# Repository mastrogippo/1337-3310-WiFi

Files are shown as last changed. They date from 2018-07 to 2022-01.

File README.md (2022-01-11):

## 1337 3310 WiFi PCB and schematics

Writeup and pics [here](http://www.mastrogippo.it/2018/07/more-adventures-with-nokia-3310-teaser/) and [here](http://www.mastrogippo.it/2018/07/1337-3310-wifi-hardware-design/)

ESP32 firmware [here](https://github.com/IHCcamp/ihc-badge-esp32)

STM32 firmware [here](https://github.com/IHCcamp/ihc-badge-STM32)

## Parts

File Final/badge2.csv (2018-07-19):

 | Qty | Value | Device | Package | Parts | Description | ARROW_PART_NUMBER | ARROW_PRICE/STOCK | DESCRIPTION | HEIGHT | MANUFACTURER_NAME | MANUFACTURER_PART_NUMBER | MPN | OC_FARNELL | OC_NEWARK | PACKAGE | PROD_ID | RS_PART_NUMBER | RS_PRICE/STOCK | SF_ID | SPICEPREFIX | SUPPLIER | VALUE
x | 1 |  | CONN_01POGOPIN_HOLE_0.58 | 1X01_POGOPIN_HOLE_0.58_DIA | J3 | Single connection point. Often used as Generic Header-pin footprint for 0.1 inch spaced/style header connections
x | 1 |  | USB_MICRO-B_SMT | USB-MICROB | J1 | USB Type Micro-B Connector |  |  |  |  |  |  |  |  |  |  | CONN-09505 |  |  | PRT-08533
x | 1 | 0 | R-EU_R0603 | R0603 | R10 | RESISTOR, European symbol |  |  |  |  |  |  |  |  |  |  |  |  |  |  | R
x | 1 | 1.6nH | C-EUC0603K | C0603K | L1 | CAPACITOR, European symbol |  |  |  |  |  |  |  |  |  |  |  |  |  |  | C
x | 5 | 100K 1/10W | SMD-RES-100K-5%-1/10W(0603) | R0603 | R12, R13, R14, R15, R17 | 301010089 |  |  |  |  |  |  | RC0603JR-07100KL |  |  |  |  |  |  |  |  |  | 100K 1/10W
x | 9 | 100nf | CERAMIC-100NF-50V-10%-X7R(0603) | C0603 | C5, C9, C10, C11, C15, C19, C20, C22, C25 | 302010138 |  |  |  |  |  |  | CC0603KRX7R9BB104 |  |  |  |  |  |  |  |  |  | 100nf
x | 6 | 10K | SMD-RES-10K-1%-1/10W(0603) | R0603 | R5, R9, R11, R16, R18, R19 | 301010299 |  |  |  |  |  |  | RC0603FR-0710KL |  |  |  |  |  |  |  |  |  | 10K
x | 1 | 10K | SMD-RES-10K-5%-1/10W(0603) | R0603 | R8 | 301010293 |  |  |  |  |  |  | RC0603JR-0710KL |  |  |  |  |  |  |  |  |  | 10K 1/10W
x | 2 | 18pF | 18PF-0603-50V-5% | 603 | C12, C13 | 18pF ceramic capacitors |  |  |  |  |  |  |  |  |  |  | CAP-08267 |  |  |  |  |  | 18pF
x | 1 | 2.7p | C-EUC0603 | C0603 | C16 | CAPACITOR, European symbol |  |  |  |  |  |  |  |  |  |  |  |  |  |  | C
x | 4 | 22R | SMD-RES-22R-5%-1/10W(0603) | R0603 | R1, R2, R6, R7 | 301010289 |  |  |  |  |  |  | RC0603JR-0722RL |  |  |  |  |  |  |  |  |  | 22R
x | 3 | 22uf | TANTALUM-SMD-22UF-16V(AVX-B) | AVX-B | C18, C23, C24 | 302020013 |  |  |  |  |  |  | TAJB226*016#NJ |  |  |  |  |  |  |  |  |  | 22uf
x | 1 | 2K | SMD-RES-1.5K-1%-1/10W(0603) | R0603 | R3 | 301010189 |  |  |  |  |  |  | RC0603FR-071K5L |  |  |  |  |  |  |  |  |  | 1.5K
x | 1 | 2K | SMD-RES-2K-1%-1/10W(0603) | R0603 | R4 | 301010221 |  |  |  |  |  |  | RC0603FR-072KL |  |  |  |  |  |  |  |  |  | 2K
x | 1 | 3310PANEL | 3310PANEL | 3310LCD | U$1
x | 1 | 4.7PF | CERAMIC-4.7PF-50V-0.25PF-NPO(0603) | C0603 | C17 | 302010091 |  |  |  |  |  |  | CC0603CRNPO9BN4R7 |  |  |  |  |  |  |  |  |  | 4.7PF
x | 1 | 4.7uf | CERAMIC-10UF-10V-10%-X5R(0603) | C0603 | C14 | 302010103 |  |  |  |  |  |  | CC0603KRX5R6BB106 |  |  |  |  |  |  |  |  |  | 10uf
x | 9 | 4.7uf | CERAMIC-4.7UF-10V-10%-X5R(0603) | C0603 | C1, C2, C3, C4, C6, C7, C8, C21, C26 | 302010111 |  |  |  |  |  |  | CC0603KRX5R6BB475 |  |  |  |  |  |  |  |  |  | 4.7uf
x | 1 | 8MHz | CRYSTAL-8MHZSMD-5X3.2 | CRYSTAL-SMD-5X3.2-4PAD | Y1 | 8MHz Crystal |  |  |  |  |  |  |  |  |  |  | XTAL-09431 |  |  |  |  |  | 8MHz
x | 3 | CJ2302 | SMD-MOSFET-N-CH-20V-2.1A-CJ2302(SOT-23) | SOT-23 | Q1, Q2, Q4 | 305030015 |  |  |  |  |  |  | CJ2302 |  |  |  |  |  |  |  |  |  | CJ2302
x | 1 | CJT1117-3.3-SOT223 | PMIC-CJT1117-3.3(SOT223) | SOT-223 | U$6 | 310030097 |  |  |  |  |  |  | CJT1117-3.3 |  |  |  |  |  |  |  |  |  | CJT1117-3.3-SOT223
x | 1 | ESP32-PICO-D4 | ESP32-PICO-D4 | ESP32-PICO-D4_1 | IC1 | ESP32-PICO-D4 module | ESP32-PICO-D4 |  | ESP32-PICO-D4 module | mm | Espressif | ESP32-PICO-D4
x | 1 | FDN340P | SMD-MOSFET-P-CH-20V-2A-FDN340P(SOT-23) | SOT-23 | Q3 | 305030026 |  |  |  |  |  |  | FDN340P |  |  |  |  |  |  |  |  |  | FDN340P
x | 3 | FIDUCIAL1.5X3 | FIDUCIAL1.5X3 | FIDUCIAL-1.5X3 | FID1, FID2, FID3 | Fiducial Alignment Points
x | 1 | INVERTED_F_ANTENNA+2 | INVERTED_F_ANTENNA+2 | DN007+2 | U$3 | 2.4GHz Inverted F Antenna
x | 1 | JST-09-PIN-HORIZONTAL | JST-09-PIN-HORIZONTAL | JST-09-SMD-HORI-1.0MM | U$4
x | 4 | LED-BOTTOM-1206 | LED-BOTTOM-1206 | LED-1206 | D4, D5, D6, D7
x | 1 | MCP73831 | MCP73831 | SOT23-5 | U3 | MCP73831T Li-Ion, Li-Pol Controller |  |  |  |  |  |  |  |  |  |  | IC-09995
x | 3 | NRVTS245ESFT3G | SMD-DIODE-SCHOTTKY-20V-1A(SOD-123) | SOD-123 | D1, D2, D3 | 304020034 |  |  |  |  |  |  | B5819W |  |  |  |  |  |  |  |  |  | 20V-1A
x | 1 | STM32F103CBT6 | STM32F103CBT6 | QFP50P900X900X160-48N | U2 | Medium-density performance line ARM-based 32-bit MCU |  |  |  |  |  |  | STM32F103CBT6 | 1606327 | 11N8296 | QFP-48 |  |  |  |  |  | STMICROELECTRONICS
x | 6 | TEST-POINT3X4 | TEST-POINT3X4 | PAD.03X.04 | TP1, TP2, TP3, TP4, TP5, TP6 | SparkFun Test Points
x | 1 | U-FL | ANTENNA-CONN-U-FL(3P) | U-FL3P-SMD-2.6X2.6X1.0MM | ANT1 | 320110048 |  |  |  |  |  |  |  |  |  |  |  |  |  |  |  |  | U-FL
x | 1 | WIRELESS-LORA-RFM95W#SMD | WIRELESS-LORA-RFM95W#SMD | WIRELESS-LORA-RFM95W#SMD | U$2 | 868/915 MHz LoRa Radio Transceiver Module based on SX1276 chip

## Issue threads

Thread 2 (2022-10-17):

Ordering the pcb's

sgoudsme, 2022-10-17:
Hi,
I'm interested in building one of these 3310 ESP boards.
I'm a  software engineer, familiar with esp-idf on eps32. So, programming the espressif will not be a problem.
I just want to know: I see that you describe some "problems" in the pcb, probably because it was the first prototype. But I see that (comparing the foto's and the gerber files) there is eg a ufl connector on gerber. Does this mean you have fixed the problems, but not tested them?
The thing I want the know in essence, If i order the pcb's online via eg jlcpcb, do you think there is a need of a rework or should it work as is? I don't need any guarantees, but more knowing that -as good as you've tested it- that it should work?

I don't find any contact information of you, you can always contact me at sibrecht@goudsmedt.be

Regards,
Sibrecht

mastrogippo, 2022-10-19:
Hi Sibrecht, as far as I remember, in the latest version everything works except for the buzzer. You'll have to short C26 and make sure you don't turn on the buzzer pin with a DC signal, or you'll burn it (it's a speaker, not a piezo).
I should have some spare PCBs, I can send you some if you cover shipping costs. Feel free to write me at [my name]@[my name].it
Cheers

Closed 2022-10-19.

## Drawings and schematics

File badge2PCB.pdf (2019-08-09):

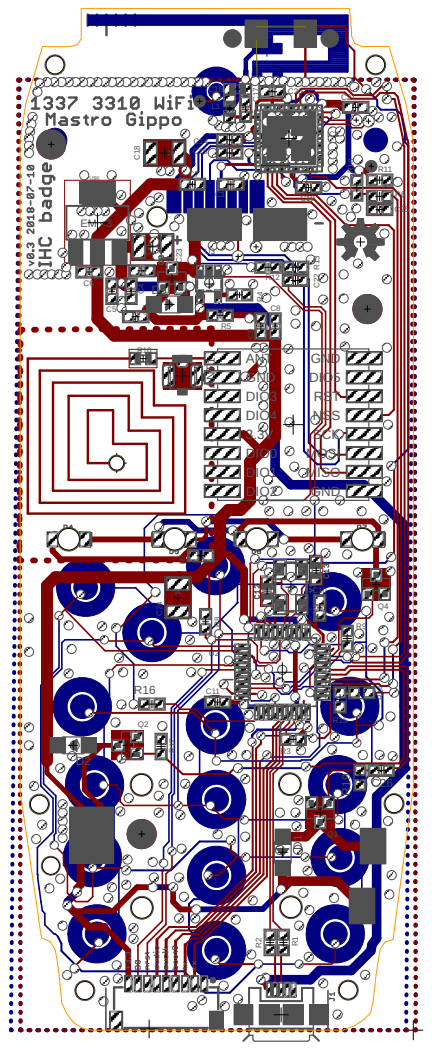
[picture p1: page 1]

GND MISO MOSI SCK NSS RST DIO5 GND
3.3V DIO4 DIO3 GND

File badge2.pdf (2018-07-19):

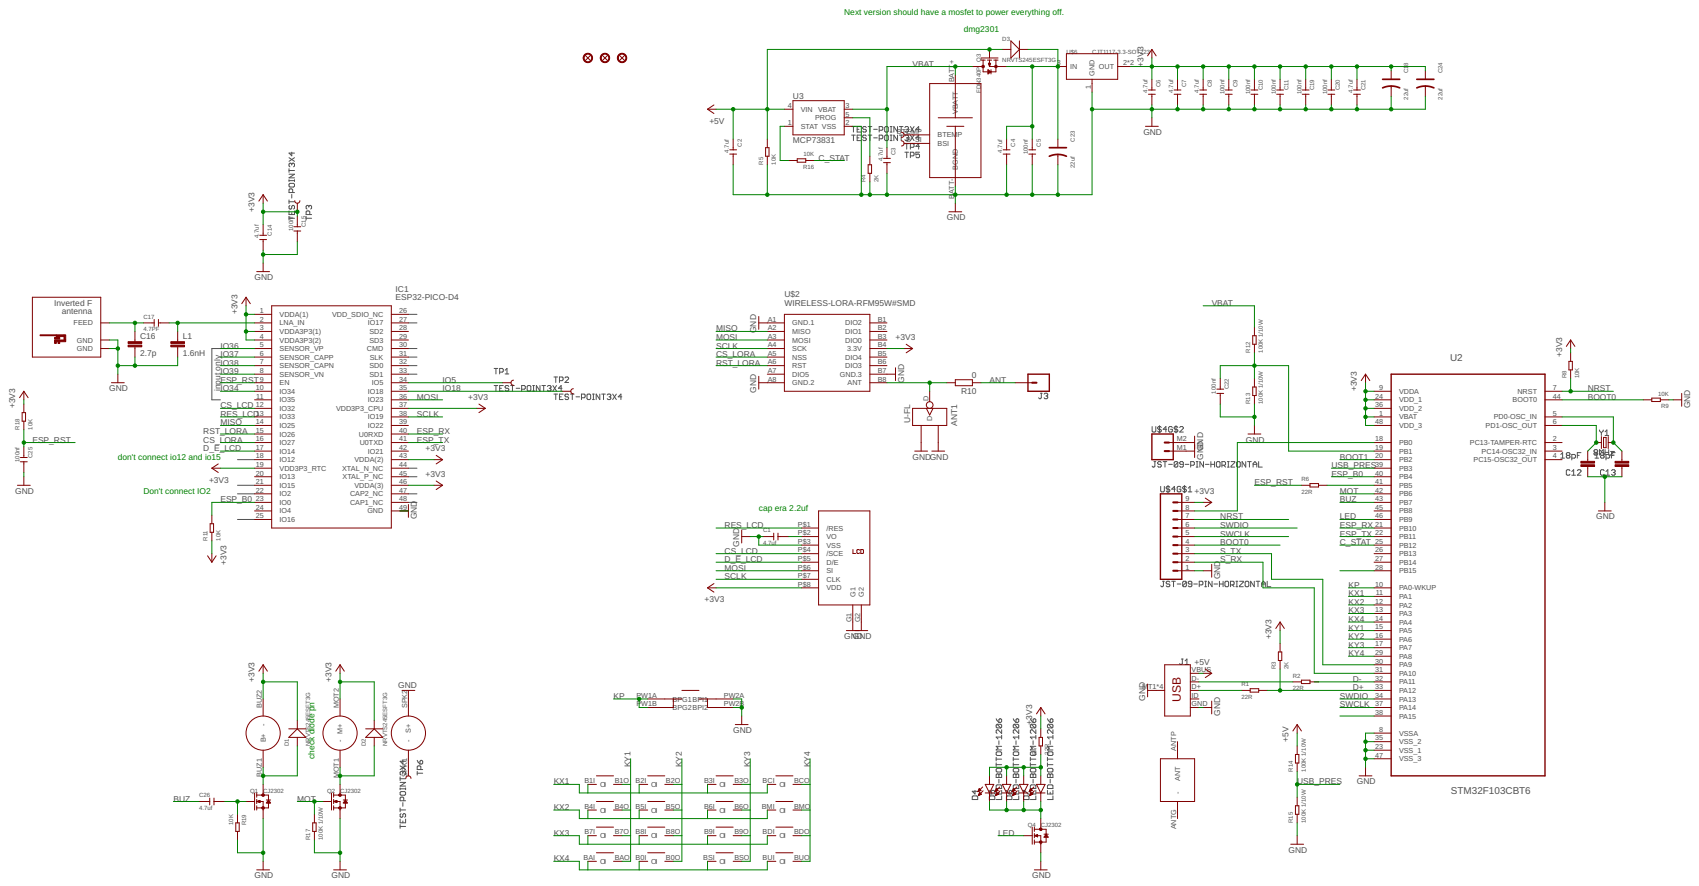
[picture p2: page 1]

Next version should have a mosfet to power everything off.

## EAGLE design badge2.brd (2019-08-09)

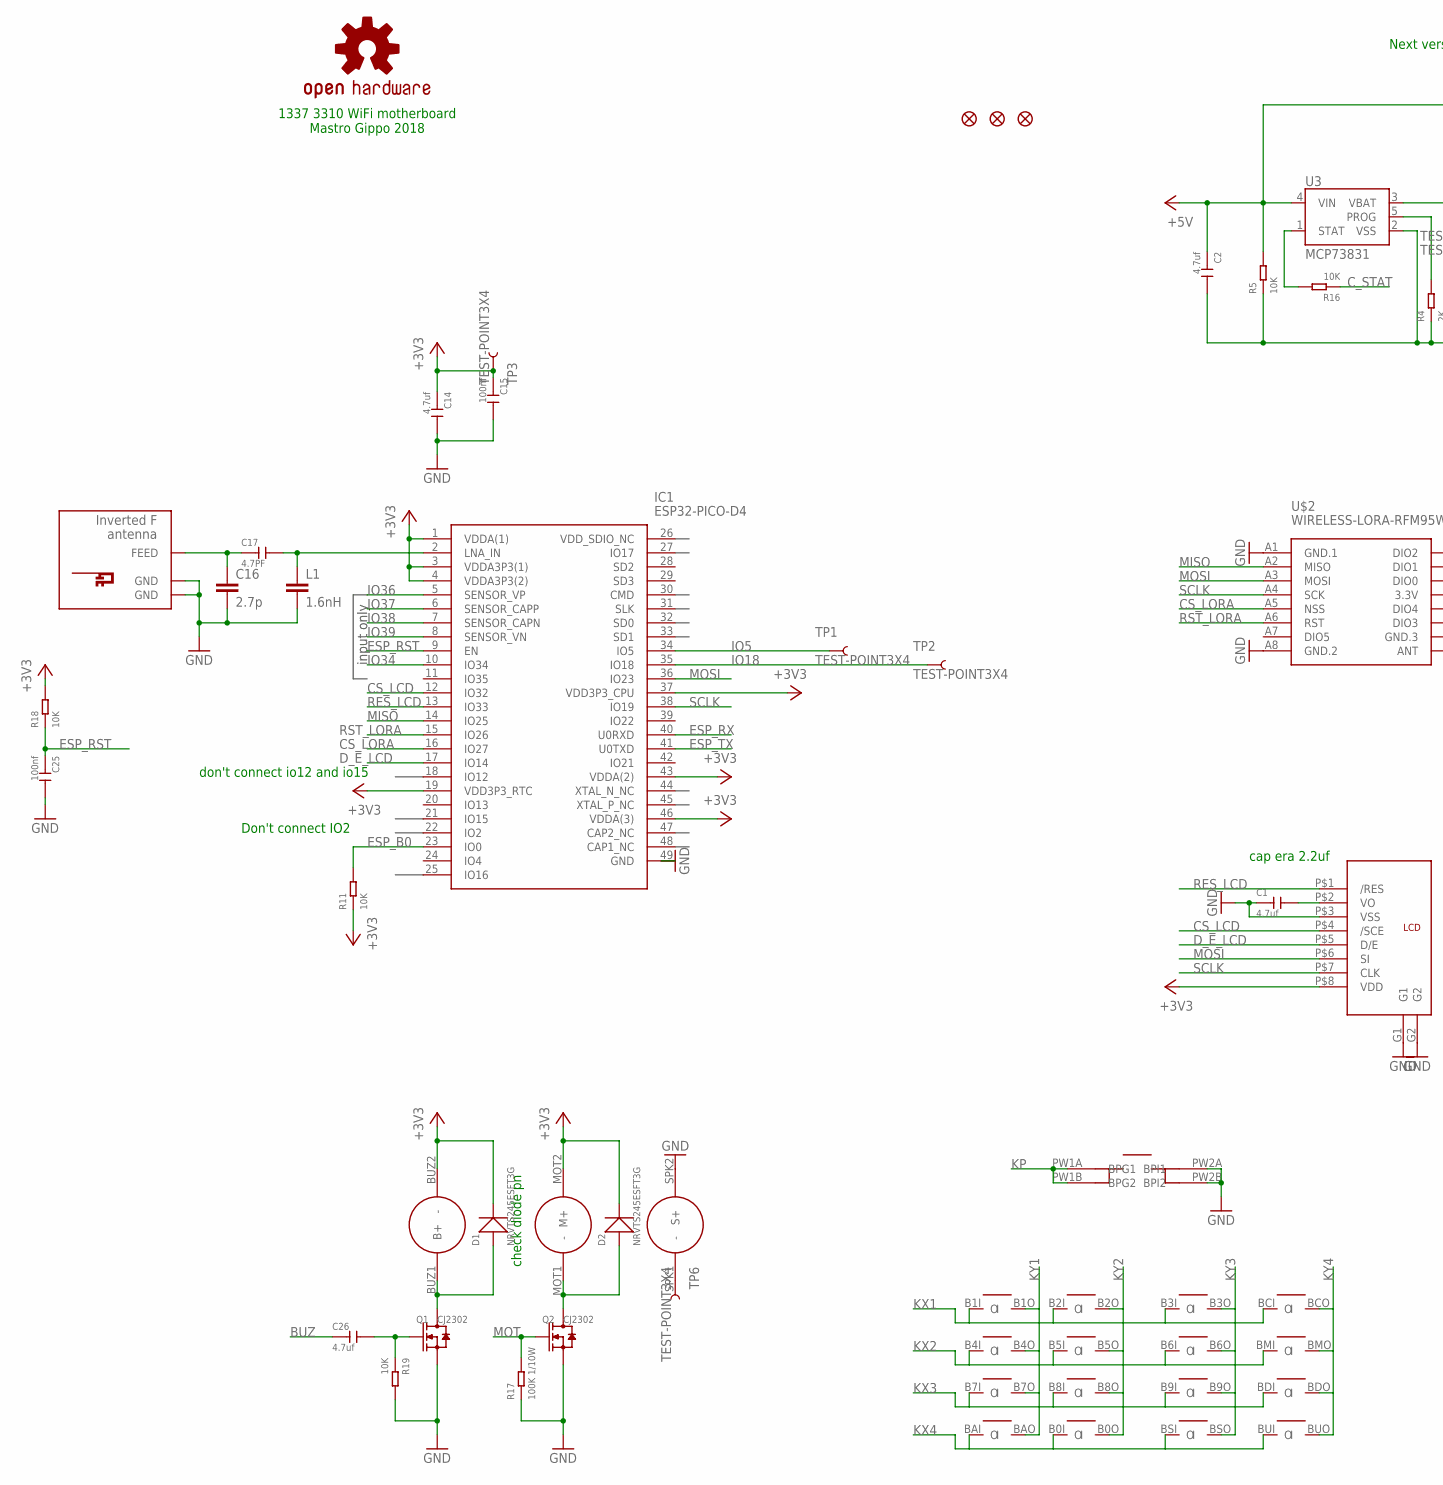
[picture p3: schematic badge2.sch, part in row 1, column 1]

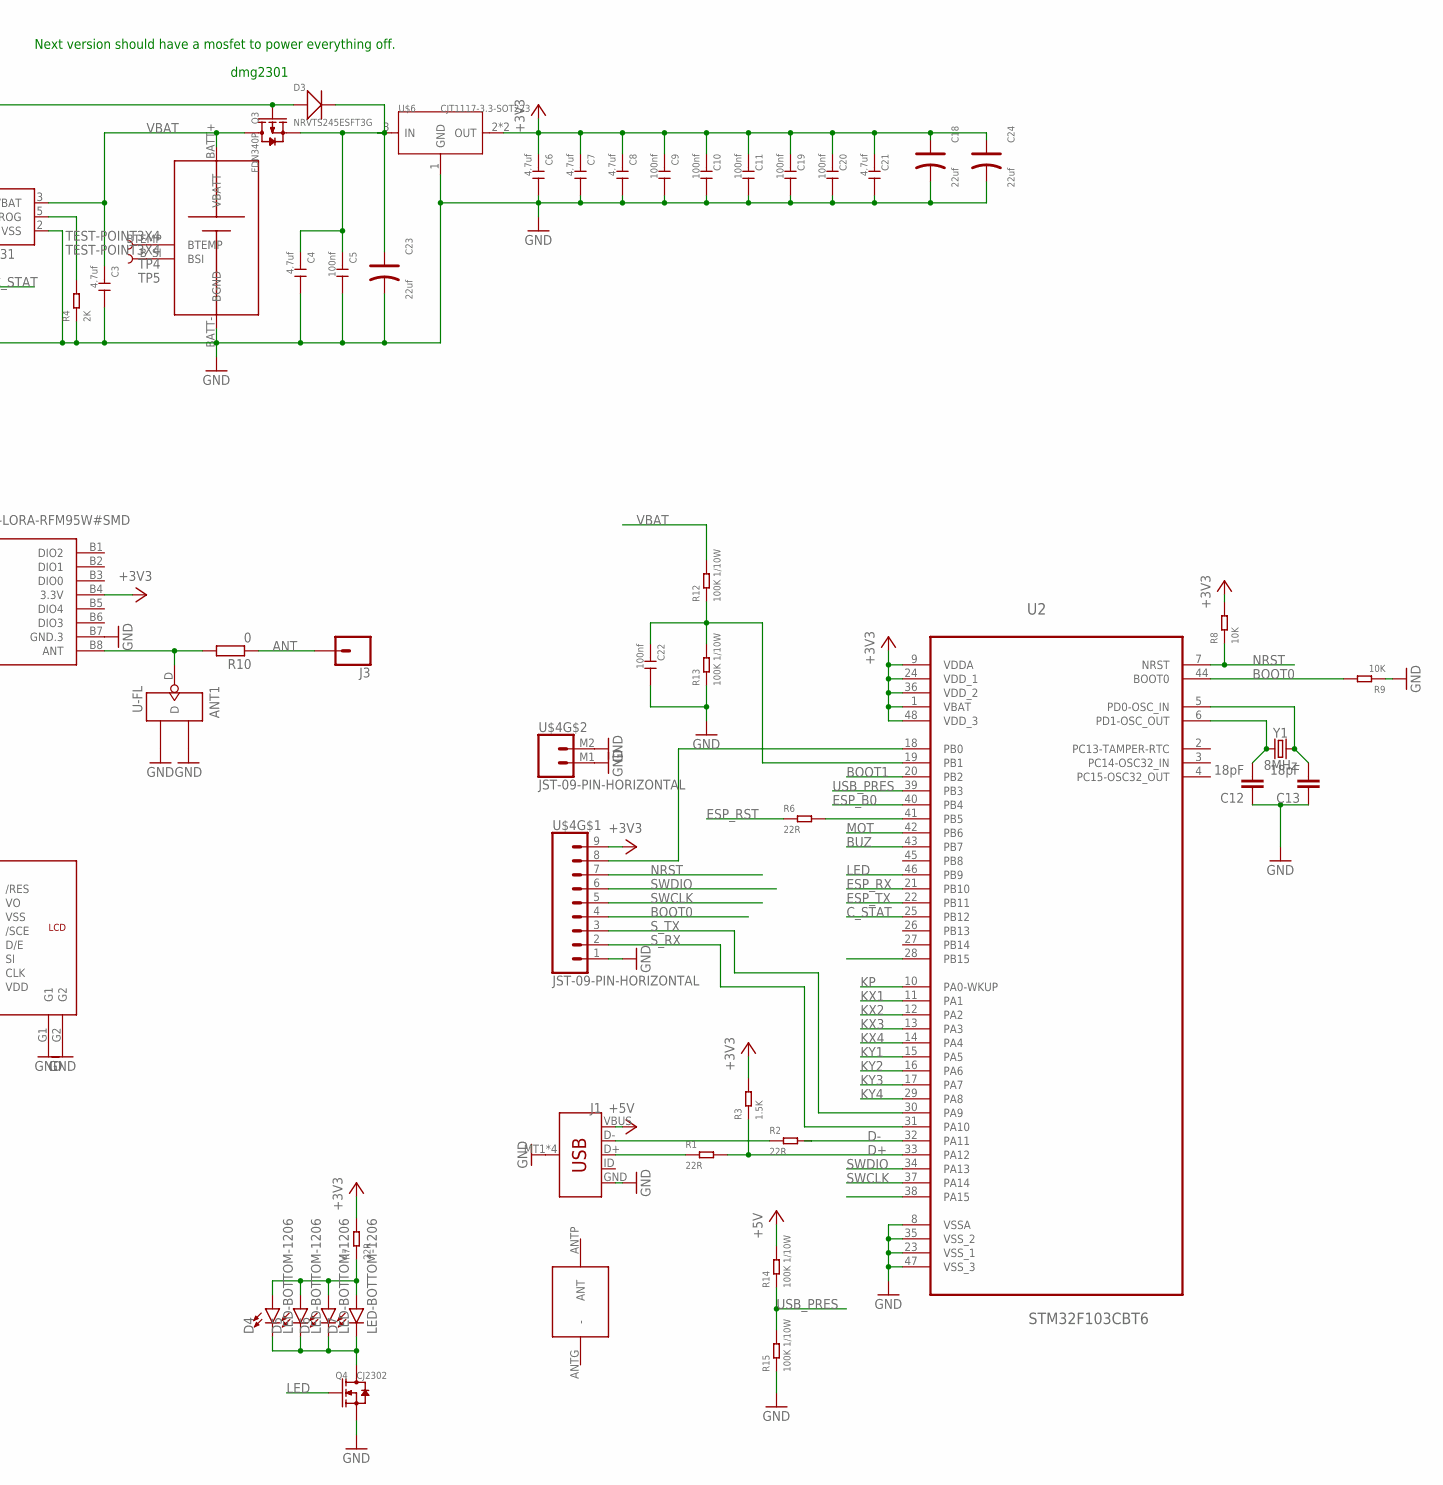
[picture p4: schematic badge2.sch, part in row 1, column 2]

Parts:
ANT1: U-FL; U-FL3P-SMD-2.6X2.6X1.0MM
C1, C2, C3, C4, C6, C7, C8, C14, C21, C26: 4.7uf; C0603
C5, C9, C10, C11, C15, C19, C20, C22, C25: 100nf; C0603
C12, C13: 18pF; 0603
C16: 2.7p; C0603
C17: 4.7PF; C0603
C18, C23, C24: 22uf; AVX-B
D1, D2, D3: NRVTS245ESFT3G; SOD-123
D4, D5, D6, D7: LED-BOTTOM-1206; LED-1206
FID1, FID2, FID3: FIDUCIAL1.5X3; FIDUCIAL-1.5X3
IC1: ESP32-PICO-D4; ESP32-PICO-D4_1
J1: USB_MICRO-B_SMT; USB-MICROB
J3: CONN_01POGOPIN_HOLE_0.58; 1X01_POGOPIN_HOLE_0.58_DIA
L1: 1.6nH; C0603K
LOGO1: OSHW-LOGOM; OSHW-LOGO-M
Q1, Q2, Q4: CJ2302; SOT-23
Q3: FDN340P; SOT-23
R1, R2, R6, R7: 22R; R0603
R3: 1.5K; R0603
R4: 2K; R0603
R5, R8, R9, R11, R16, R18, R19: 10K; R0603
R10: 0; R0603
R12, R13, R14, R15, R17: 100K 1/10W; R0603
TP1, TP2, TP3, TP4, TP5, TP6: TEST-POINT3X4; PAD.03X.04
U2: STM32F103CBT6; QFP50P900X900X160-48N
U3: MCP73831; SOT23-5
U$1: 3310PANEL; 3310LCD
U$2: WIRELESS-LORA-RFM95W#SMD
U$3: INVERTED_F_ANTENNA+2; DN007+2
U$4: JST-09-PIN-HORIZONTAL; JST-09-SMD-HORI-1.0MM
U$6: CJT1117-3.3-SOT223; SOT-223
Y1: 8MHz; CRYSTAL-SMD-5X3.2-4PAD

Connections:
+3V3: C6.1, C7.1, C8.1, C9.1, C10.1, C11.1, C14.1, C15.1, C18.+, C19.1, C20.1, C21.1, C24.+, D1.-, D2.-, IC1.1 (VDDA(1)), IC1.3 (VDDA3P3(1)), IC1.4 (VDDA3P3(2)), IC1.19 (VDD3P3_RTC), IC1.37 (VDD3P3_CPU), IC1.43 (VDDA(2)), IC1.46 (VDDA(3)), R3.2, R7.2, R8.2, R11.1, R18.2, TP3.P$1, U2.1 (VBAT), U2.9 (VDDA), U2.24 (VDD_1), U2.36 (VDD_2), U2.48 (VDD_3), U$1.BUZ2 (-), U$1.MOT2 (M+), U$1.P$8 (VDD), U$2.B4 (3.3V), U$4.9, U$6.2 (OUT), U$6.TER (OUT)
+5V: C2.1, D3.+, J1.VBUS, Q3.1 (G), R5.2, R14.2, U3.4 (VIN)
ANT: J3.1, R10.1
BOOT0: R9.2, U2.44 (BOOT0), U$4.4
BOOT1: U2.20 (PB2)
BUZ: C26.1, U2.43 (PB7)
CS_LCD: IC1.12 (IO32), U$1.P$4 (/SCE)
CS_LORA: IC1.16 (IO27), U$2.A5 (NSS)
C_STAT: R16.1, U2.25 (PB12)
D+: R1.2, R3.1, U2.33 (PA12)
D-: R2.2, U2.32 (PA11)
D_E_LCD: IC1.17 (IO14), U$1.P$5 (D/E)
ESP_B0: IC1.23 (IO0), R11.2, U2.40 (PB4)
ESP_RST: C25.1, IC1.9 (EN), R6.1, R18.1
ESP_RX: IC1.40 (U0RXD), U2.21 (PB10)
ESP_TX: IC1.41 (U0TXD), U2.22 (PB11)
GND: ANT1.GND1, ANT1.GND2, C1.1, C2.2, C3.2, C4.2, C5.2, C6.2, C7.2, C8.2, C9.2, C10.2, C11.2, C12.1, C13.1, C14.2, C15.2, C16.2, C18.-, C19.2, C20.2, C21.2, C22.2, C23.-, C24.-, C25.2, IC1.49 (GND), J1.GND, J1.MT1 (SHIELD), J1.MT2 (SHIELD), J1.P$1 (SHIELD), J1.P$2 (SHIELD), L1.2, Q1.2 (S), Q2.2 (S), Q4.2 (S), R4.1, R5.1, R9.1, R13.1, R15.1, R17.1, R19.2, U2.8 (VSSA), U2.23 (VSS_1), U2.35 (VSS_2), U2.47 (VSS_3), U3.2 (VSS), U$1.BATT- (BGND), U$1.G1, U$1.G2, U$1.P$3 (VSS), U$1.PW2A (BPI1), U$1.PW2B (BPI2), U$1.SPK2 (S+), U$2.A1 (GND.1), U$2.A8 (GND.2), U$2.B7 (GND.3), U$3.GND, U$3.GND@1 (GND), U$4.1, U$4.M1 (1), U$4.M2 (2), U$6.1 (GND)
IO5: IC1.34 (IO5), TP1.P$1
IO18: IC1.35 (IO18), TP2.P$1
IO34: IC1.10 (IO34)
IO36: IC1.5 (SENSOR_VP)
IO37: IC1.6 (SENSOR_CAPP)
IO38: IC1.7 (SENSOR_CAPN)
IO39: IC1.8 (SENSOR_VN)
KP: U2.10 (PA0-WKUP), U$1.PW1A (BPG1), U$1.PW1B (BPG2)
KX1: U2.11 (PA1), U$1.B1I (I), U$1.B2I (I), U$1.B3I (I), U$1.BCI (I)
KX2: U2.12 (PA2), U$1.B4I (I), U$1.B5I (I), U$1.B6I (I), U$1.BMI (I)
KX3: U2.13 (PA3), U$1.B7I (I), U$1.B8I (I), U$1.B9I (I), U$1.BDI (I)
KX4: U2.14 (PA4), U$1.B0I (I), U$1.BAI (I), U$1.BSI (I), U$1.BUI (I)
KY1: U2.15 (PA5), U$1.B1O (O), U$1.B4O (O), U$1.B7O (O), U$1.BAO (O)
KY2: U2.16 (PA6), U$1.B0O (O), U$1.B2O (O), U$1.B5O (O), U$1.B8O (O)
KY3: U2.17 (PA7), U$1.B3O (O), U$1.B6O (O), U$1.B9O (O), U$1.BSO (O)
KY4: U2.29 (PA8), U$1.BCO (O), U$1.BDO (O), U$1.BMO (O), U$1.BUO (O)
LED: Q4.1 (G), U2.46 (PB9)
MISO: IC1.14 (IO25), U$2.A2 (MISO)
MOSI: IC1.36 (IO23), U$1.P$6 (SI), U$2.A3 (MOSI)
MOT: Q2.1 (G), R17.2, U2.42 (PB6)
unnamed: C1.2, U$1.P$2 (VO)
unnamed: C16.1, C17.1, U$3.FEED
unnamed: C17.2, IC1.2 (LNA_IN), L1.1
unnamed: ANT1.D, R10.2, U$2.B8 (ANT)
unnamed: J1.D+, R1.1
unnamed: J1.D-, R2.1
unnamed: R16.2, U3.1 (STAT)
unnamed: C26.2, Q1.1 (G), R19.1
unnamed: D1.+, Q1.3 (D), U$1.BUZ1 (B+)
unnamed: C13.2, U2.5 (PD0-OSC_IN), Y1.3 (2)
unnamed: TP4.P$1, U$1.BTEMP
unnamed: D2.+, Q2.3 (D), U$1.MOT1 (-)
unnamed: R4.2, U3.5 (PROG)
unnamed: C4.1, C5.1, C23.+, D3.-, Q3.2 (S), U$6.3 (IN)
unnamed: C12.2, U2.6 (PD1-OSC_OUT), Y1.1
unnamed: U2.18 (PB0), U$4.8
unnamed: TP6.P$1, U$1.SPK1 (-)
unnamed: R6.2, U2.41 (PB5)
unnamed: TP5.P$1, U$1.B_SI (BSI)
unnamed: D4.C, D5.C, D6.C, D7.C, Q4.3 (D)
unnamed: D4.A, D5.A, D6.A, D7.A, R7.1
unnamed: C22.1, R12.1, R13.2, U2.19 (PB1)
NRST: R8.1, U2.7 (NRST), U$4.7
RES_LCD: IC1.13 (IO33), U$1.P$1 (/RES)
RST_LORA: IC1.15 (IO26), U$2.A6 (RST)
SCLK: IC1.38 (IO19), U$1.P$7 (CLK), U$2.A4 (SCK)
SWCLK: U2.37 (PA14), U$4.5
SWDIO: U2.34 (PA13), U$4.6
S_RX: U2.31 (PA10), U$4.2
S_TX: U2.30 (PA9), U$4.3
USB_PRES: R14.1, R15.2, U2.39 (PB3)
VBAT: C3.1, Q3.3 (D), R12.2, U3.3 (VBAT), U$1.BATT+ (VBATT)

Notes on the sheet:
check diode pn
input only
Don't connect IO2
don't connect io12 and io15
dmg2301
cap era 2.2uf
Next version should have a mosfet to power everything off.
1337 3310 WiFi motherboard Mastro Gippo 2018

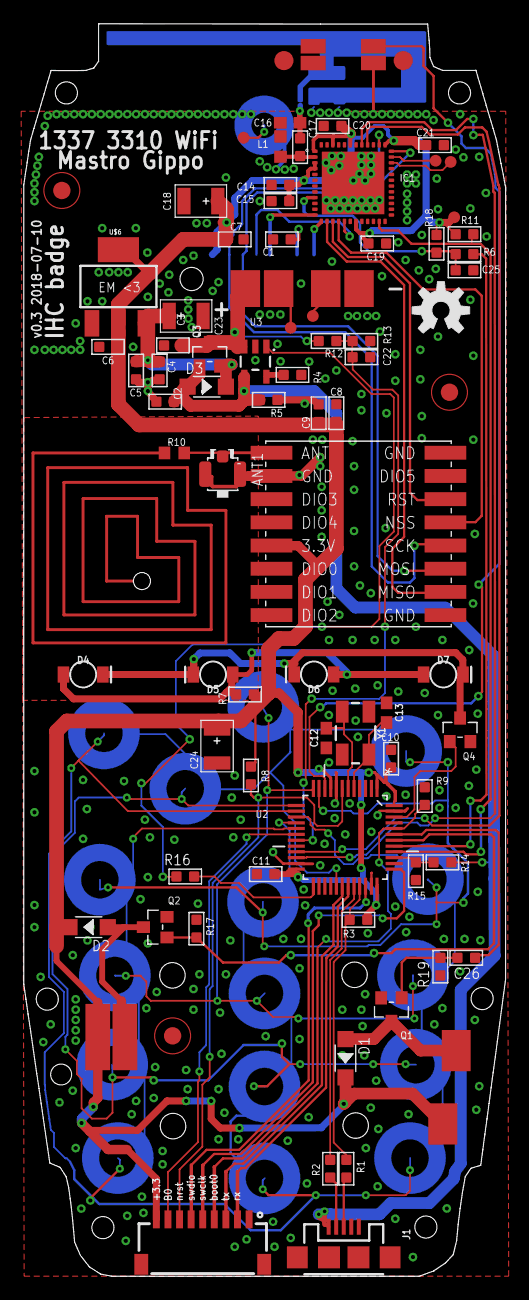
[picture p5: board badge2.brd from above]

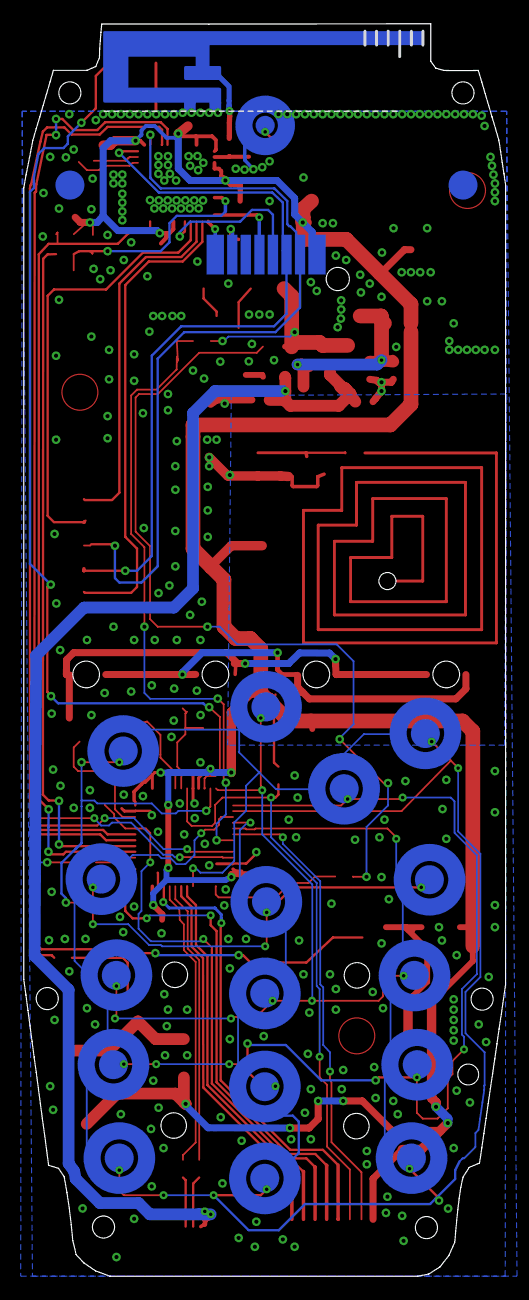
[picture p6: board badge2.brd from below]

Board: 2 copper layers, 41.6 x 108.0 mm, 79 parts (2 on the bottom side), 63 nets.

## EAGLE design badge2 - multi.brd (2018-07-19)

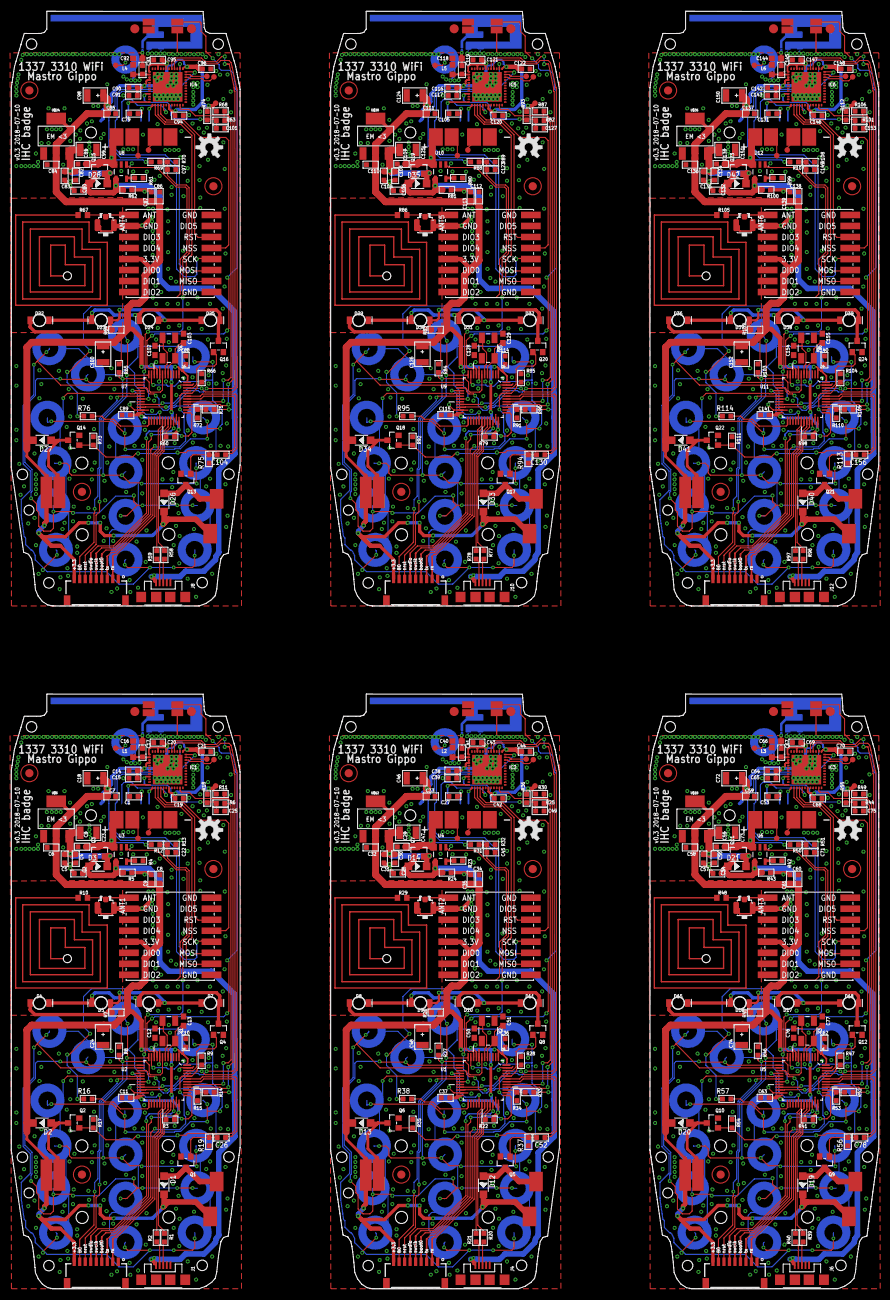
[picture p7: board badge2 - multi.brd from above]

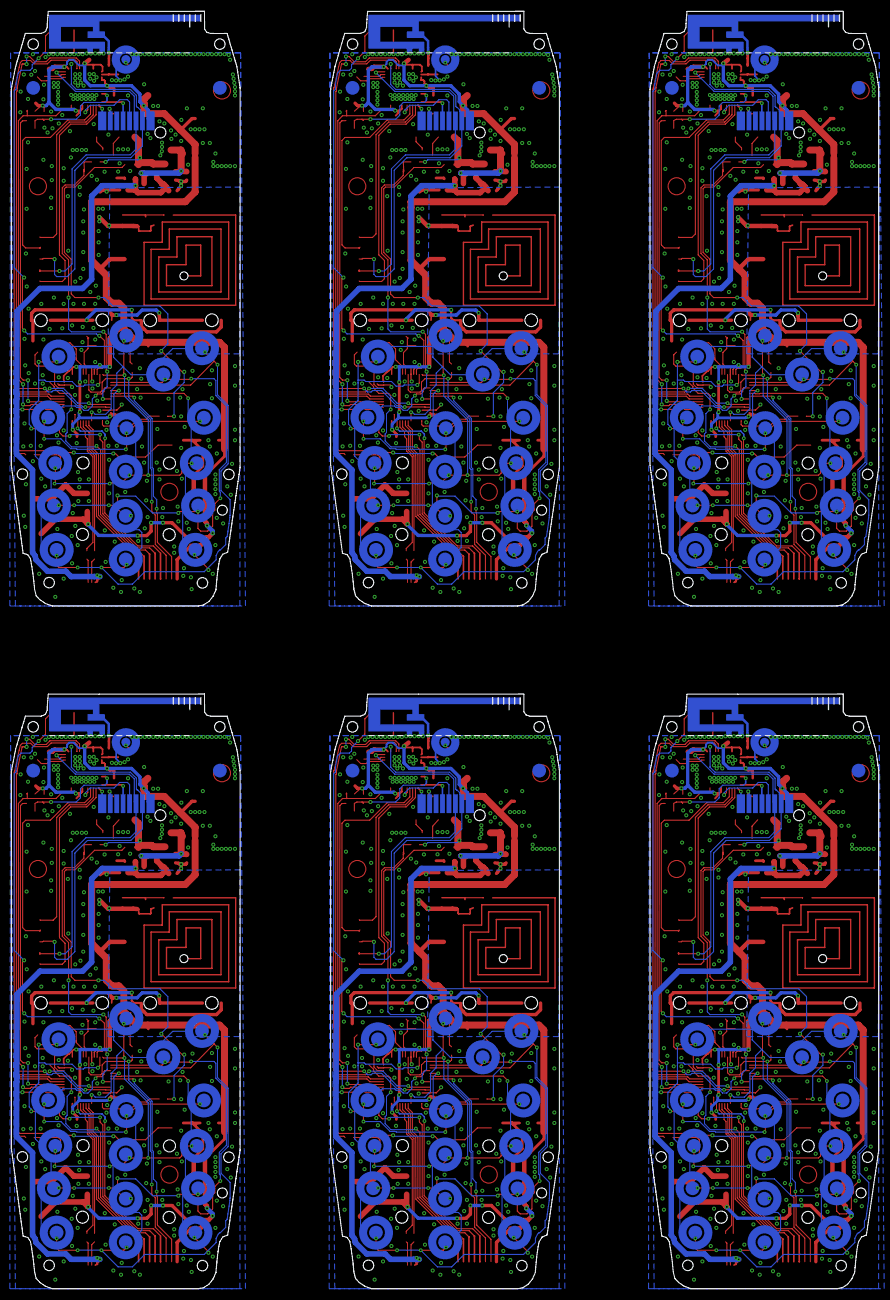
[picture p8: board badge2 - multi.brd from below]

Board: 2 copper layers, 474 parts (12 on the bottom side), 378 nets.

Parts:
ANT1, ANT2, ANT3, ANT4, ANT5, ANT6: U-FL; U-FL3P-SMD-2.6X2.6X1.0MM
C1, C2, C3, C4, C6, C7, C8, C21, C26, C27, C28, C29, C30, C32, C33, C34, C44, C52, C53, C54, C55, C56, C58, C59, C60, C70, C78, C79, C80, C81, C82, C84, C85, C86, C96, C104, C105, C106, C107, C108, C110, C111, C112, C122, C130, C131, C132, C133, C134, C136, C137, C138, C148, C156: 4.7uf; C0603
C5, C9, C10, C11, C15, C19, C20, C22, C25, C31, C35, C36, C37, C39, C42, C43, C45, C49, C57, C61, C62, C63, C65, C68, C69, C71, C75, C83, C87, C88, C89, C91, C94, C95, C97, C101, C109, C113, C114, C115, C117, C120, C121, C123, C127, C135, C139, C140, C141, C143, C146, C147, C149, C153: 100nf; C0603
C12, C13, C50, C51, C76, C77, C102, C103, C128, C129, C154, C155: 18pF; 0603
C14, C38, C64, C90, C116, C142: 10uf; C0603
C16, C40, C66, C92, C118, C144: 2.7p; C0603
C17, C41, C67, C93, C119, C145: 4.7PF; C0603
C18, C23, C24, C46, C47, C48, C72, C73, C74, C98, C99, C100, C124, C125, C126, C150, C151, C152: 22uf; AVX-B
D1, D2, D3, D12, D13, D14, D19, D20, D21, D26, D27, D28, D33, D34, D35, D40, D41, D42: NRVTS245ESFT3G; SOD-123
D4, D5, D6, D7, D8, D9, D10, D11, D15, D16, D17, D18, D22, D23, D24, D25, D29, D30, D31, D32, D36, D37, D38, D39: LED-BOTTOM-1206; LED-1206
FID1, FID2, FID3, FID4, FID5, FID6, FID7, FID8, FID9, FID10, FID11, FID12, FID13, FID14, FID15, FID16, FID17, FID18: FIDUCIAL1.5X3; FIDUCIAL-1.5X3
IC1, IC2, IC3, IC4, IC5, IC6: ESP32-PICO-D4; ESP32-PICO-D4_1
J1, J4, J6, J8, J10, J12: USB-MICROB
J2, J3, J5, J7, J9, J11: 1X01_POGOPIN_HOLE_0.58_DIA
L1, L2, L3, L4, L5, L6: 1.6nH; C0603K
Q1, Q2, Q4, Q5, Q6, Q8, Q9, Q10, Q12, Q13, Q14, Q16, Q17, Q18, Q20, Q21, Q22, Q24: CJ2302; SOT-23
Q3, Q7, Q11, Q15, Q19, Q23: FDN340P; SOT-23
R1, R2, R6, R7, R20, R21, R25, R26, R39, R40, R44, R45, R58, R59, R63, R64, R77, R78, R82, R83, R96, R97, R101, R102: 22R; R0603
R3, R22, R41, R60, R79, R98: 1.5K; R0603
R4, R23, R42, R61, R80, R99: 2K; R0603
R5, R9, R11, R16, R18, R19, R24, R28, R30, R36, R37, R38, R43, R47, R49, R55, R56, R57, R62, R66, R68, R74, R75, R76, R81, R85, R87, R93, R94, R95, R100, R104, R106, R112, R113, R114: 10K; R0603
R8, R27, R46, R65, R84, R103: 10K 1/10W; R0603
R10, R29, R48, R67, R86, R105: 0; R0603
R12, R13, R14, R15, R17, R31, R32, R33, R34, R35, R50, R51, R52, R53, R54, R69, R70, R71, R72, R73, R88, R89, R90, R91, R92, R107, R108, R109, R110, R111: 100K 1/10W; R0603
TP1, TP2, TP3, TP4, TP5, TP6, TP7, TP8, TP9, TP10, TP11, TP12, TP13, TP14, TP15, TP16, TP17, TP18, TP19, TP20, TP21, TP22, TP23, TP24, TP25, TP26, TP27, TP28, TP29, TP30, TP31, TP32, TP33, TP34, TP35, TP36: TEST-POINT3X4; PAD.03X.04
U1, U2, U5, U7, U9, U11: STM32F103CBT6; QFP50P900X900X160-48N
U3, U4, U6, U8, U10, U12: MCP73831; SOT23-5
U$1, U$7, U$13, U$19, U$25, U$31: 3310PANEL; 3310LCD
U$2, U$8, U$14, U$20, U$26, U$32: WIRELESS-LORA-RFM95W#SMD
U$3, U$9, U$15, U$21, U$27, U$33: INVERTED_F_ANTENNA+2; DN007+2
U$4, U$10, U$16, U$22, U$28, U$34: JST-09-PIN-HORIZONTAL; JST-09-SMD-HORI-1.0MM
U$5, U$11, U$17, U$23, U$29, U$35: OSHW-LOGO-M
U$6, U$12, U$18, U$24, U$30, U$36: CJT1117-3.3-SOT223; SOT-223
Y1, Y2, Y3, Y4, Y5, Y6: 8MHz; CRYSTAL-SMD-5X3.2-4PAD

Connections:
+3V1: C32.1, C33.1, C34.1, C35.1, C36.1, C37.1, C38.1, C39.1, C42.1, C43.1, C44.1, C46.+, C48.+, D12.-, D13.-, IC2.1, IC2.3, IC2.4, IC2.19, IC2.37, IC2.43, IC2.46, R22.2, R26.2, R27.2, R30.1, R36.2, TP9.P$1, U1.1, U1.9, U1.24, U1.36, U1.48, U$7.BUZ2, U$7.MOT2, U$7.P$8, U$8.B4, U$10.9, U$12.2, U$12.TER
+3V2: C58.1, C59.1, C60.1, C61.1, C62.1, C63.1, C64.1, C65.1, C68.1, C69.1, C70.1, C72.+, C74.+, D19.-, D20.-, IC3.1, IC3.3, IC3.4, IC3.19, IC3.37, IC3.43, IC3.46, R41.2, R45.2, R46.2, R49.1, R55.2, TP15.P$1, U5.1, U5.9, U5.24, U5.36, U5.48, U$13.BUZ2, U$13.MOT2, U$13.P$8, U$14.B4, U$16.9, U$18.2, U$18.TER
+3V3: C6.1, C7.1, C8.1, C9.1, C10.1, C11.1, C14.1, C15.1, C18.+, C19.1, C20.1, C21.1, C24.+, D1.-, D2.-, IC1.1, IC1.3, IC1.4, IC1.19, IC1.37, IC1.43, IC1.46, R3.2, R7.2, R8.2, R11.1, R18.2, TP3.P$1, U2.1, U2.9, U2.24, U2.36, U2.48, U$1.BUZ2, U$1.MOT2, U$1.P$8, U$2.B4, U$4.9, U$6.2, U$6.TER
+3V4: C84.1, C85.1, C86.1, C87.1, C88.1, C89.1, C90.1, C91.1, C94.1, C95.1, C96.1, C98.+, C100.+, D26.-, D27.-, IC4.1, IC4.3, IC4.4, IC4.19, IC4.37, IC4.43, IC4.46, R60.2, R64.2, R65.2, R68.1, R74.2, TP21.P$1, U7.1, U7.9, U7.24, U7.36, U7.48, U$19.BUZ2, U$19.MOT2, U$19.P$8, U$20.B4, U$22.9, U$24.2, U$24.TER
+3V5: C110.1, C111.1, C112.1, C113.1, C114.1, C115.1, C116.1, C117.1, C120.1, C121.1, C122.1, C124.+, C126.+, D33.-, D34.-, IC5.1, IC5.3, IC5.4, IC5.19, IC5.37, IC5.43, IC5.46, R79.2, R83.2, R84.2, R87.1, R93.2, TP27.P$1, U9.1, U9.9, U9.24, U9.36, U9.48, U$25.BUZ2, U$25.MOT2, U$25.P$8, U$26.B4, U$28.9, U$30.2, U$30.TER
+3V6: C136.1, C137.1, C138.1, C139.1, C140.1, C141.1, C142.1, C143.1, C146.1, C147.1, C148.1, C150.+, C152.+, D40.-, D41.-, IC6.1, IC6.3, IC6.4, IC6.19, IC6.37, IC6.43, IC6.46, R98.2, R102.2, R103.2, R106.1, R112.2, TP33.P$1, U11.1, U11.9, U11.24, U11.36, U11.48, U$31.BUZ2, U$31.MOT2, U$31.P$8, U$32.B4, U$34.9, U$36.2, U$36.TER
+5V: C2.1, D3.+, J1.VBUS, Q3.1, R5.2, R14.2, U3.4
+5V1: C28.1, D14.+, J4.VBUS, Q7.1, R24.2, R33.2, U4.4
+5V2: C54.1, D21.+, J6.VBUS, Q11.1, R43.2, R52.2, U6.4
+5V3: C80.1, D28.+, J8.VBUS, Q15.1, R62.2, R71.2, U8.4
+5V4: C106.1, D35.+, J10.VBUS, Q19.1, R81.2, R90.2, U10.4
+5V5: C132.1, D42.+, J12.VBUS, Q23.1, R100.2, R109.2, U12.4
ANT: J3.1, R10.1
ANT1: J2.1, R29.1
ANT2: J5.1, R48.1
ANT3: J7.1, R67.1
ANT4: J9.1, R86.1
ANT5: J11.1, R105.1
BOOT0: R9.2, U2.44, U$4.4
BOOT3: R28.2, U1.44, U$10.4
BOOT5: R47.2, U5.44, U$16.4
BOOT7: R66.2, U7.44, U$22.4
BOOT9: R85.2, U9.44, U$28.4
BOOT11: R104.2, U11.44, U$34.4
BUZ: C26.1, U2.43
BUZ1: C52.1, U1.43
BUZ2: C78.1, U5.43
BUZ3: C104.1, U7.43
BUZ4: C130.1, U9.43
BUZ5: C156.1, U11.43
CS_LCD: IC1.12, U$1.P$4
CS_LCD1: IC2.12, U$7.P$4
CS_LCD2: IC3.12, U$13.P$4
CS_LCD3: IC4.12, U$19.P$4
CS_LCD4: IC5.12, U$25.P$4
CS_LCD5: IC6.12, U$31.P$4
CS_LORA: IC1.16, U$2.A5
CS_LORA1: IC2.16, U$8.A5
CS_LORA2: IC3.16, U$14.A5
CS_LORA3: IC4.16, U$20.A5
CS_LORA4: IC5.16, U$26.A5
CS_LORA5: IC6.16, U$32.A5
C_STAT: R16.1, U2.25
C_STAT1: R38.1, U1.25
C_STAT2: R57.1, U5.25
C_STAT3: R76.1, U7.25
C_STAT4: R95.1, U9.25
C_STAT5: R114.1, U11.25
D+: R1.2, R3.1, U2.33
D+1: R20.2, R22.1, U1.33
D+2: R39.2, R41.1, U5.33
D+3: R58.2, R60.1, U7.33
D+4: R77.2, R79.1, U9.33
D+5: R96.2, R98.1, U11.33
D-: R2.2, U2.32
D-1: R21.2, U1.32
D-2: R40.2, U5.32
D-3: R59.2, U7.32
D-4: R78.2, U9.32
D-5: R97.2, U11.32
D_E_LCD: IC1.17, U$1.P$5
D_E_LCD1: IC2.17, U$7.P$5
D_E_LCD2: IC3.17, U$13.P$5
D_E_LCD3: IC4.17, U$19.P$5
D_E_LCD4: IC5.17, U$25.P$5
D_E_LCD5: IC6.17, U$31.P$5
ESP_B0: IC1.23, R11.2, U2.40
ESP_B1: IC2.23, R30.2, U1.40
ESP_B2: IC3.23, R49.2, U5.40
ESP_B3: IC4.23, R68.2, U7.40
ESP_B4: IC5.23, R87.2, U9.40
ESP_B5: IC6.23, R106.2, U11.40
ESP_RST: C25.1, IC1.9, R6.1, R18.1
ESP_RST1: C49.1, IC2.9, R25.1, R36.1
ESP_RST2: C75.1, IC3.9, R44.1, R55.1
ESP_RST3: C101.1, IC4.9, R63.1, R74.1
ESP_RST4: C127.1, IC5.9, R82.1, R93.1
ESP_RST5: C153.1, IC6.9, R101.1, R112.1
ESP_RX: IC1.40, U2.21
ESP_RX1: IC2.40, U1.21
ESP_RX2: IC3.40, U5.21
ESP_RX3: IC4.40, U7.21
ESP_RX4: IC5.40, U9.21
ESP_RX5: IC6.40, U11.21
ESP_TX: IC1.41, U2.22
ESP_TX1: IC2.41, U1.22
ESP_TX2: IC3.41, U5.22
ESP_TX3: IC4.41, U7.22
ESP_TX4: IC5.41, U9.22
ESP_TX5: IC6.41, U11.22
GND: ANT1.GND1, ANT1.GND2, C1.1, C2.2, C3.2, C4.2, C5.2, C6.2, C7.2, C8.2, C9.2, C10.2, C11.2, C12.1, C13.1, C14.2, C15.2, C16.2, C18.-, C19.2, C20.2, C21.2, C22.2, C23.-, C24.-, C25.2, IC1.49, J1.GND, J1.MT1, J1.MT2, J1.P$1, J1.P$2, L1.2, Q1.2, Q2.2, Q4.2, R4.1, R5.1, R9.1, R13.1, R15.1, R17.1, R19.2, U2.8, U2.23, U2.35, U2.47, U3.2, U$1.BATT-, U$1.G1, U$1.G2, U$1.P$3, U$1.PW2A, U$1.PW2B, U$1.SPK2, U$2.A1, U$2.A8, U$2.B7, U$3.GND, U$3.GND@1, U$4.1, U$4.M1, U$4.M2, U$6.1
GND1: ANT2.GND1, ANT2.GND2, C27.1, C28.2, C29.2, C30.2, C31.2, C32.2, C33.2, C34.2, C35.2, C36.2, C37.2, C38.2, C39.2, C40.2, C42.2, C43.2, C44.2, C45.2, C46.-, C47.-, C48.-, C49.2, C50.1, C51.1, IC2.49, J4.GND, J4.MT1, J4.MT2, J4.P$1, J4.P$2, L2.2, Q5.2, Q6.2, Q8.2, R23.1, R24.1, R28.1, R32.1, R34.1, R35.1, R37.2, U1.8, U1.23, U1.35, U1.47, U4.2, U$7.BATT-, U$7.G1, U$7.G2, U$7.P$3, U$7.PW2A, U$7.PW2B, U$7.SPK2, U$8.A1, U$8.A8, U$8.B7, U$9.GND, U$9.GND@1, U$10.1, U$10.M1, U$10.M2, U$12.1
GND2: ANT3.GND1, ANT3.GND2, C53.1, C54.2, C55.2, C56.2, C57.2, C58.2, C59.2, C60.2, C61.2, C62.2, C63.2, C64.2, C65.2, C66.2, C68.2, C69.2, C70.2, C71.2, C72.-, C73.-, C74.-, C75.2, C76.1, C77.1, IC3.49, J6.GND, J6.MT1, J6.MT2, J6.P$1, J6.P$2, L3.2, Q9.2, Q10.2, Q12.2, R42.1, R43.1, R47.1, R51.1, R53.1, R54.1, R56.2, U5.8, U5.23, U5.35, U5.47, U6.2, U$13.BATT-, U$13.G1, U$13.G2, U$13.P$3, U$13.PW2A, U$13.PW2B, U$13.SPK2, U$14.A1, U$14.A8, U$14.B7, U$15.GND, U$15.GND@1, U$16.1, U$16.M1, U$16.M2, U$18.1
GND3: ANT4.GND1, ANT4.GND2, C79.1, C80.2, C81.2, C82.2, C83.2, C84.2, C85.2, C86.2, C87.2, C88.2, C89.2, C90.2, C91.2, C92.2, C94.2, C95.2, C96.2, C97.2, C98.-, C99.-, C100.-, C101.2, C102.1, C103.1, IC4.49, J8.GND, J8.MT1, J8.MT2, J8.P$1, J8.P$2, L4.2, Q13.2, Q14.2, Q16.2, R61.1, R62.1, R66.1, R70.1, R72.1, R73.1, R75.2, U7.8, U7.23, U7.35, U7.47, U8.2, U$19.BATT-, U$19.G1, U$19.G2, U$19.P$3, U$19.PW2A, U$19.PW2B, U$19.SPK2, U$20.A1, U$20.A8, U$20.B7, U$21.GND, U$21.GND@1, U$22.1, U$22.M1, U$22.M2, U$24.1
GND4: ANT5.GND1, ANT5.GND2, C105.1, C106.2, C107.2, C108.2, C109.2, C110.2, C111.2, C112.2, C113.2, C114.2, C115.2, C116.2, C117.2, C118.2, C120.2, C121.2, C122.2, C123.2, C124.-, C125.-, C126.-, C127.2, C128.1, C129.1, IC5.49, J10.GND, J10.MT1, J10.MT2, J10.P$1, J10.P$2, L5.2, Q17.2, Q18.2, Q20.2, R80.1, R81.1, R85.1, R89.1, R91.1, R92.1, R94.2, U9.8, U9.23, U9.35, U9.47, U10.2, U$25.BATT-, U$25.G1, U$25.G2, U$25.P$3, U$25.PW2A, U$25.PW2B, U$25.SPK2, U$26.A1, U$26.A8, U$26.B7, U$27.GND, U$27.GND@1, U$28.1, U$28.M1, U$28.M2, U$30.1
GND5: ANT6.GND1, ANT6.GND2, C131.1, C132.2, C133.2, C134.2, C135.2, C136.2, C137.2, C138.2, C139.2, C140.2, C141.2, C142.2, C143.2, C144.2, C146.2, C147.2, C148.2, C149.2, C150.-, C151.-, C152.-, C153.2, C154.1, C155.1, IC6.49, J12.GND, J12.MT1, J12.MT2, J12.P$1, J12.P$2, L6.2, Q21.2, Q22.2, Q24.2, R99.1, R100.1, R104.1, R108.1, R110.1, R111.1, R113.2, U11.8, U11.23, U11.35, U11.47, U12.2, U$31.BATT-, U$31.G1, U$31.G2, U$31.P$3, U$31.PW2A, U$31.PW2B, U$31.SPK2, U$32.A1, U$32.A8, U$32.B7, U$33.GND, U$33.GND@1, U$34.1, U$34.M1, U$34.M2, U$36.1
IO5: IC1.34, TP1.P$1
IO7: IC2.34, TP7.P$1
IO8: IC2.35, TP8.P$1
IO14: IC3.34, TP13.P$1
IO15: IC3.35, TP14.P$1
IO18: IC1.35, TP2.P$1
IO22: IC4.34, TP19.P$1
IO23: IC4.35, TP20.P$1
IO29: IC5.34, TP25.P$1
IO30: IC5.35, TP26.P$1
IO41: IC6.34, TP31.P$1
IO42: IC6.35, TP32.P$1
KP: U2.10, U$1.PW1A, U$1.PW1B
KP1: U1.10, U$7.PW1A, U$7.PW1B
KP2: U5.10, U$13.PW1A, U$13.PW1B
KP3: U7.10, U$19.PW1A, U$19.PW1B
KP4: U9.10, U$25.PW1A, U$25.PW1B
KP5: U11.10, U$31.PW1A, U$31.PW1B
KX1: U2.11, U$1.B1I, U$1.B2I, U$1.B3I, U$1.BCI
KX2: U2.12, U$1.B4I, U$1.B5I, U$1.B6I, U$1.BMI
KX3: U2.13, U$1.B7I, U$1.B8I, U$1.B9I, U$1.BDI
KX4: U2.14, U$1.B0I, U$1.BAI, U$1.BSI, U$1.BUI
KX5: U1.11, U$7.B1I, U$7.B2I, U$7.B3I, U$7.BCI
KX6: U1.12, U$7.B4I, U$7.B5I, U$7.B6I, U$7.BMI
KX7: U1.13, U$7.B7I, U$7.B8I, U$7.B9I, U$7.BDI
KX8: U1.14, U$7.B0I, U$7.BAI, U$7.BSI, U$7.BUI
KX9: U5.11, U$13.B1I, U$13.B2I, U$13.B3I, U$13.BCI
KX10: U5.12, U$13.B4I, U$13.B5I, U$13.B6I, U$13.BMI
KX11: U5.13, U$13.B7I, U$13.B8I, U$13.B9I, U$13.BDI
KX12: U5.14, U$13.B0I, U$13.BAI, U$13.BSI, U$13.BUI
KX13: U7.11, U$19.B1I, U$19.B2I, U$19.B3I, U$19.BCI
KX14: U7.12, U$19.B4I, U$19.B5I, U$19.B6I, U$19.BMI
KX15: U7.13, U$19.B7I, U$19.B8I, U$19.B9I, U$19.BDI
KX16: U7.14, U$19.B0I, U$19.BAI, U$19.BSI, U$19.BUI
KX17: U9.11, U$25.B1I, U$25.B2I, U$25.B3I, U$25.BCI
KX18: U9.12, U$25.B4I, U$25.B5I, U$25.B6I, U$25.BMI
KX19: U9.13, U$25.B7I, U$25.B8I, U$25.B9I, U$25.BDI
KX20: U9.14, U$25.B0I, U$25.BAI, U$25.BSI, U$25.BUI
KX21: U11.11, U$31.B1I, U$31.B2I, U$31.B3I, U$31.BCI
KX22: U11.12, U$31.B4I, U$31.B5I, U$31.B6I, U$31.BMI
KX23: U11.13, U$31.B7I, U$31.B8I, U$31.B9I, U$31.BDI
KX24: U11.14, U$31.B0I, U$31.BAI, U$31.BSI, U$31.BUI
KY1: U2.15, U$1.B1O, U$1.B4O, U$1.B7O, U$1.BAO
KY2: U2.16, U$1.B0O, U$1.B2O, U$1.B5O, U$1.B8O
KY3: U2.17, U$1.B3O, U$1.B6O, U$1.B9O, U$1.BSO
KY4: U2.29, U$1.BCO, U$1.BDO, U$1.BMO, U$1.BUO
KY5: U1.15, U$7.B1O, U$7.B4O, U$7.B7O, U$7.BAO
KY6: U1.16, U$7.B0O, U$7.B2O, U$7.B5O, U$7.B8O
KY7: U1.17, U$7.B3O, U$7.B6O, U$7.B9O, U$7.BSO
KY8: U1.29, U$7.BCO, U$7.BDO, U$7.BMO, U$7.BUO
KY9: U5.15, U$13.B1O, U$13.B4O, U$13.B7O, U$13.BAO
KY10: U5.16, U$13.B0O, U$13.B2O, U$13.B5O, U$13.B8O
KY11: U5.17, U$13.B3O, U$13.B6O, U$13.B9O, U$13.BSO
KY12: U5.29, U$13.BCO, U$13.BDO, U$13.BMO, U$13.BUO
KY13: U7.15, U$19.B1O, U$19.B4O, U$19.B7O, U$19.BAO
KY14: U7.16, U$19.B0O, U$19.B2O, U$19.B5O, U$19.B8O
KY15: U7.17, U$19.B3O, U$19.B6O, U$19.B9O, U$19.BSO
KY16: U7.29, U$19.BCO, U$19.BDO, U$19.BMO, U$19.BUO
KY17: U9.15, U$25.B1O, U$25.B4O, U$25.B7O, U$25.BAO
KY18: U9.16, U$25.B0O, U$25.B2O, U$25.B5O, U$25.B8O
KY19: U9.17, U$25.B3O, U$25.B6O, U$25.B9O, U$25.BSO
KY20: U9.29, U$25.BCO, U$25.BDO, U$25.BMO, U$25.BUO
KY21: U11.15, U$31.B1O, U$31.B4O, U$31.B7O, U$31.BAO
KY22: U11.16, U$31.B0O, U$31.B2O, U$31.B5O, U$31.B8O
KY23: U11.17, U$31.B3O, U$31.B6O, U$31.B9O, U$31.BSO
KY24: U11.29, U$31.BCO, U$31.BDO, U$31.BMO, U$31.BUO
LED: Q4.1, U2.46
LED1: Q8.1, U1.46
LED2: Q12.1, U5.46
LED3: Q16.1, U7.46
LED4: Q20.1, U9.46
LED5: Q24.1, U11.46
MISO: IC1.14, U$2.A2
MISO1: IC2.14, U$8.A2
MISO2: IC3.14, U$14.A2
MISO3: IC4.14, U$20.A2
MISO4: IC5.14, U$26.A2
MISO5: IC6.14, U$32.A2
MOSI: IC1.36, U$1.P$6, U$2.A3
MOSI1: IC2.36, U$7.P$6, U$8.A3
MOSI2: IC3.36, U$13.P$6, U$14.A3
MOSI3: IC4.36, U$19.P$6, U$20.A3
MOSI4: IC5.36, U$25.P$6, U$26.A3
MOSI5: IC6.36, U$31.P$6, U$32.A3
MOT: Q2.1, R17.2, U2.42
MOT1: Q6.1, R35.2, U1.42
MOT2: Q10.1, R54.2, U5.42
MOT3: Q14.1, R73.2, U7.42
MOT4: Q18.1, R92.2, U9.42
MOT5: Q22.1, R111.2, U11.42
unnamed: C1.2, U$1.P$2
unnamed: C16.1, C17.1, U$3.FEED
unnamed: C17.2, IC1.2, L1.1
unnamed: ANT1.D, R10.2, U$2.B8
unnamed: J1.D+, R1.1
unnamed: J1.D-, R2.1
unnamed: R16.2, U3.1
unnamed: C26.2, Q1.1, R19.1
unnamed: D1.+, Q1.3, U$1.BUZ1
unnamed: C13.2, U2.5, Y1.3
unnamed: TP4.P$1, U$1.BTEMP
unnamed: D2.+, Q2.3, U$1.MOT1
unnamed: R4.2, U3.5
unnamed: C4.1, C5.1, C23.+, D3.-, Q3.2, U$6.3
unnamed: C12.2, U2.6, Y1.1
unnamed: U2.18, U$4.8
unnamed: TP6.P$1, U$1.SPK1
unnamed: C27.2, U$7.P$2
unnamed: R6.2, U2.41
unnamed: TP5.P$1, U$1.B_SI
unnamed: D4.C, D5.C, D6.C, D7.C, Q4.3
unnamed: D4.A, D5.A, D6.A, D7.A, R7.1
unnamed: C22.1, R12.1, R13.2, U2.19
unnamed: J4.D+, R20.1
unnamed: J4.D-, R21.1
unnamed: D12.+, Q5.3, U$7.BUZ1
unnamed: D13.+, Q6.3, U$7.MOT1
unnamed: R23.2, U4.5
unnamed: C30.1, C31.1, C47.+, D14.-, Q7.2, U$12.3
unnamed: C40.1, C41.1, U$9.FEED
unnamed: C41.2, IC2.2, L2.1
unnamed: R25.2, U1.41
unnamed: D8.C, D9.C, D10.C, D11.C, Q8.3
unnamed: D8.A, D9.A, D10.A, D11.A, R26.1
unnamed: ANT2.D, R29.2, U$8.B8
unnamed: U1.18, U$10.8
unnamed: C45.1, R31.1, R32.2, U1.19
unnamed: TP10.P$1, U$7.BTEMP
unnamed: TP11.P$1, U$7.B_SI
unnamed: TP12.P$1, U$7.SPK1
unnamed: C51.2, U1.5, Y2.3
unnamed: C50.2, U1.6, Y2.1
unnamed: C52.2, Q5.1, R37.1
unnamed: R38.2, U4.1
unnamed: C53.2, U$13.P$2
unnamed: J6.D+, R39.1
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

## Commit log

2018-07-19 First production version
    [badge2 - multi.brd, badge2.brd, badge2.csv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]
2019-08-09 Added license
    [badge2.brd, badge2.sch]
2022-01-11 Add link to STM32 firmware

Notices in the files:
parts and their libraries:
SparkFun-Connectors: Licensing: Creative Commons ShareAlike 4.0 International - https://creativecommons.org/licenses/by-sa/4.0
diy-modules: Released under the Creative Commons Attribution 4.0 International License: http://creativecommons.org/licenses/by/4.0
